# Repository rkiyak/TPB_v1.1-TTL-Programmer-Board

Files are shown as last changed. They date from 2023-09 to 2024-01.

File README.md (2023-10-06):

# TTL Programming Board (TPB v1.1)

This README file provides an introduction and usage guide for your TTL programming board. This board is designed for programming ESP32 boards using the CH340 TTL converter IC.

<p align="center">
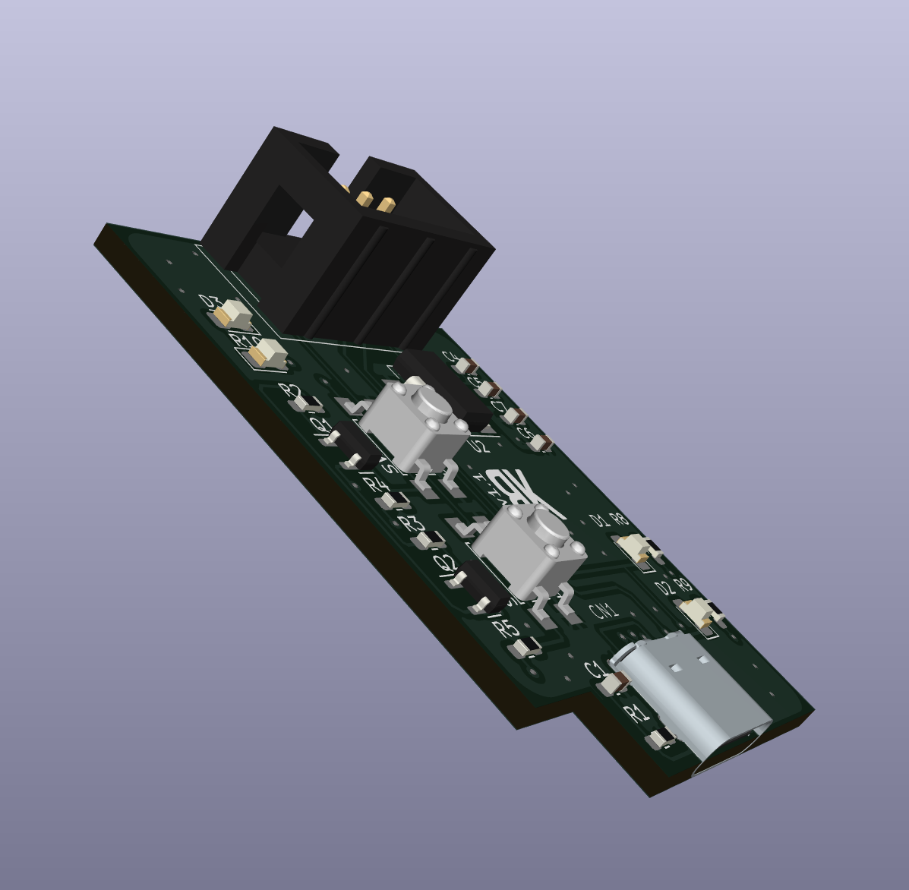
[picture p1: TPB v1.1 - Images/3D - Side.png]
3D Side Image
  
</p>

## Features

- Equipped with the CH340 TTL converter IC for programming ESP32 boards.
- Simple interface for quick and easy use.
- PCB design and connection schematics are provided.

## Connections

### Input Connector (Type-C)
- Input Voltage: 5V

### Programming Connector
The programming connector is used for programming ESP32 boards and has the following pin connections:

1. 3V3
2. TX
3. IO0
4. RX
5. GND
6. EN

These connections define the pins used for programming your ESP32 board. Please make sure to carefully connect to these pins for the programming process.

## Using the Board

Using the board is straightforward. You can program your ESP32 boards by following these steps:

1. Plug the board into the USB port.

2. Connect your ESP32 board to the TTL connection points on the board, ensuring that you follow the connection schematics.

3. Prepare your ESP32 program using Arduino IDE or a similar software.

4. Select the board and upload your program using Arduino IDE or your preferred software.

5. Once the programming process is complete, your ESP32 board is ready for use.

## Images

### Schematic

You can find the connection schematics for the board in the image below:

<p align="center">
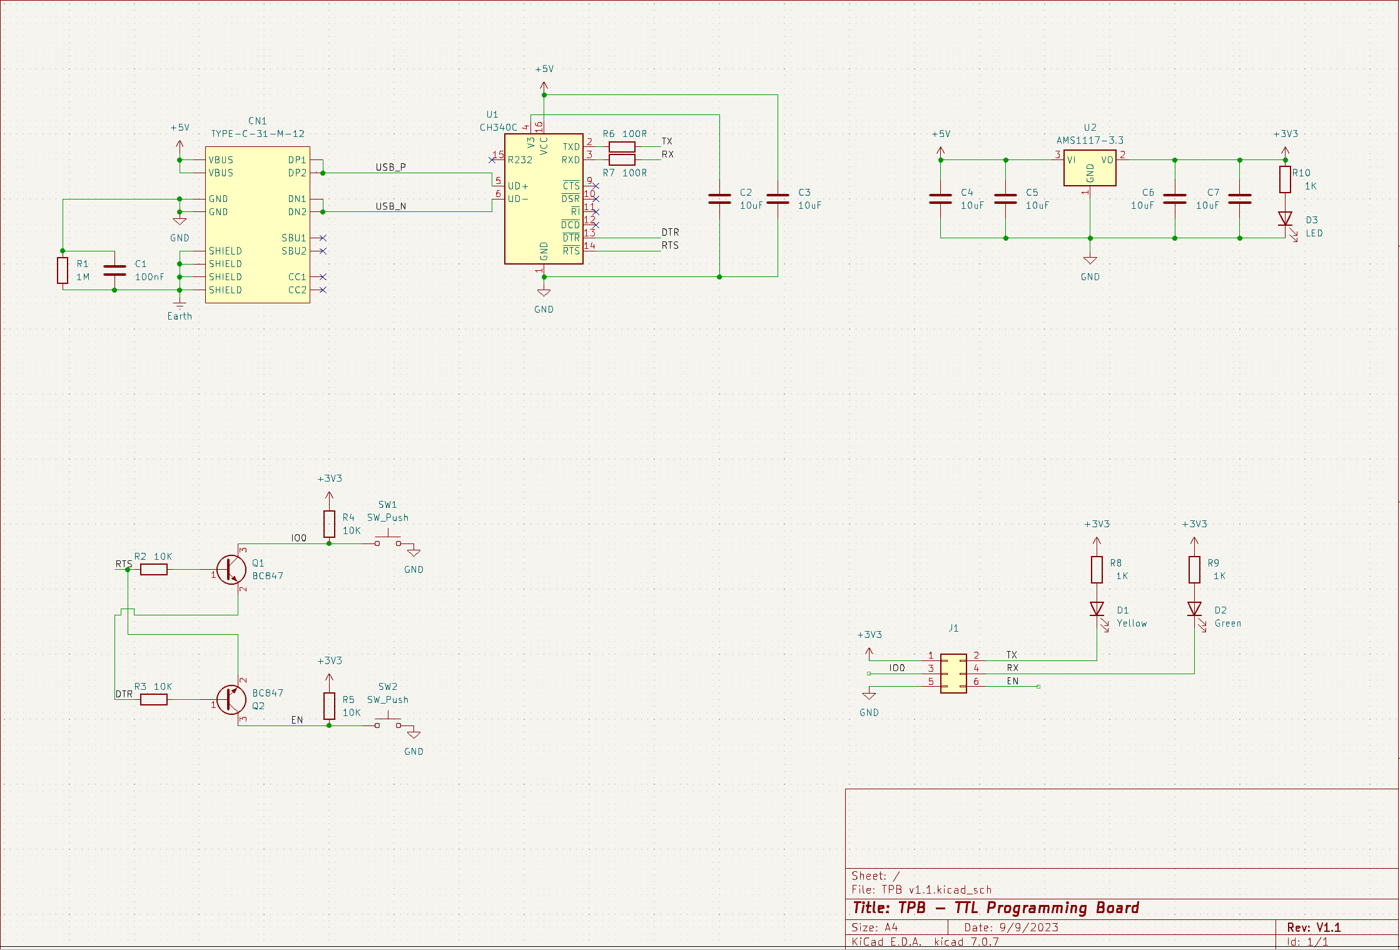
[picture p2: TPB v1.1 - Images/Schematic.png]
Schematic Image
  
</p>

### PCB Images

Below are some images of the board's PCB design:

<p align="center">
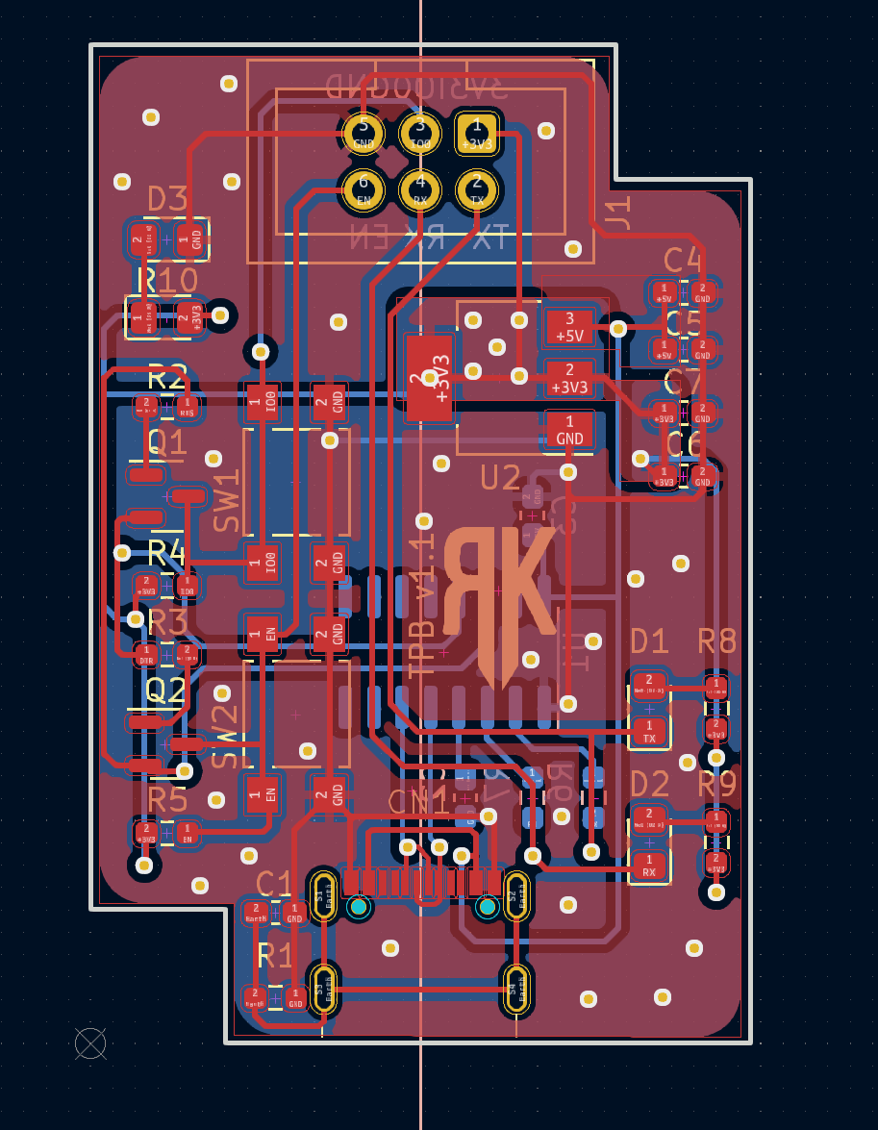
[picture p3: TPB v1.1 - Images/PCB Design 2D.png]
PCB Image 1
  
</p>

### 3D Images

Here are 3D images of the board:

<p align="center">
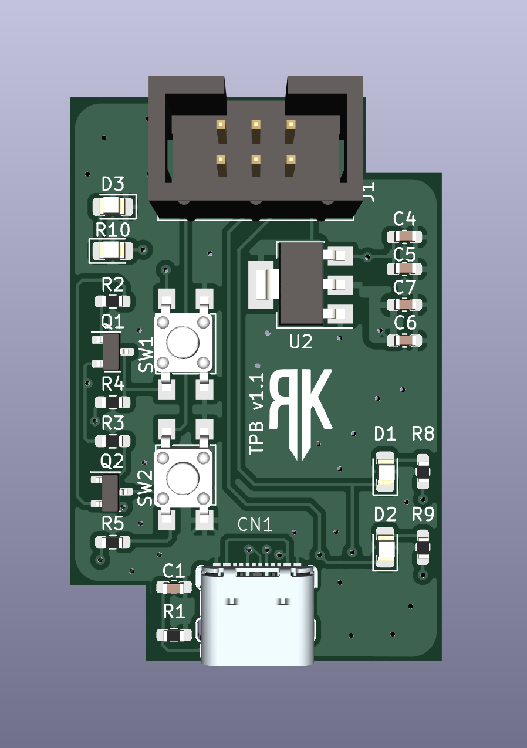
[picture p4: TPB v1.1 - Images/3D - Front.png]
3D Front Image
  
</p>

<p align="center">
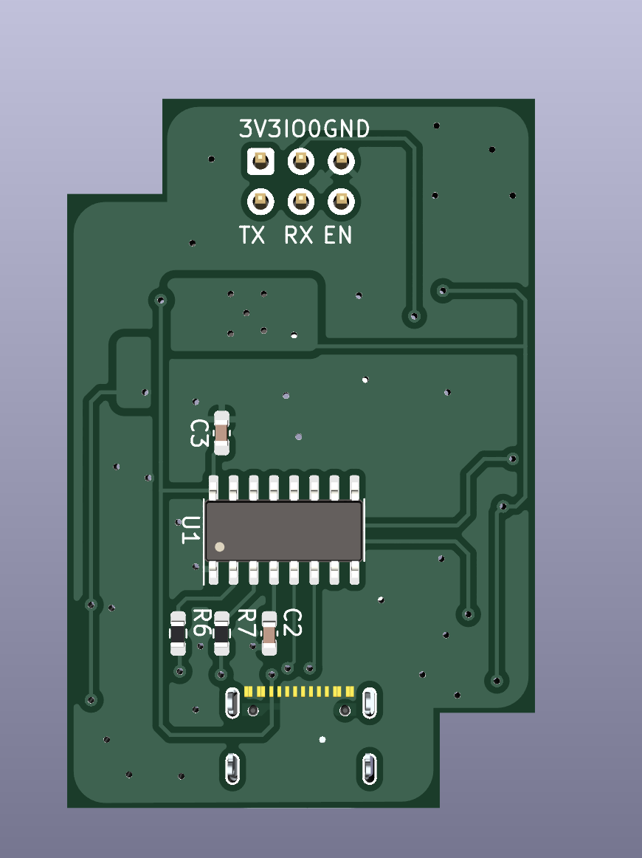
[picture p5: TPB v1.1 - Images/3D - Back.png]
3D Back Image
  
</p>

## Support

If you have any questions or need assistance with using the board, please contact us at rk@rkiyak.com.

## License

The design of this board is licensed under the Open Source license. Please review the license document and ensure compliance before using the board.

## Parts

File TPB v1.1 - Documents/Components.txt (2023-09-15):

Type C USB Connector
https://www.lcsc.com/search?q=TYPE-C-31-M-12

Serial Communication IC
https://www.lcsc.com/product-detail/USB-ICs_WCH-Jiangsu-Qin-Heng-CH340C_C84681.html

Programming Connector

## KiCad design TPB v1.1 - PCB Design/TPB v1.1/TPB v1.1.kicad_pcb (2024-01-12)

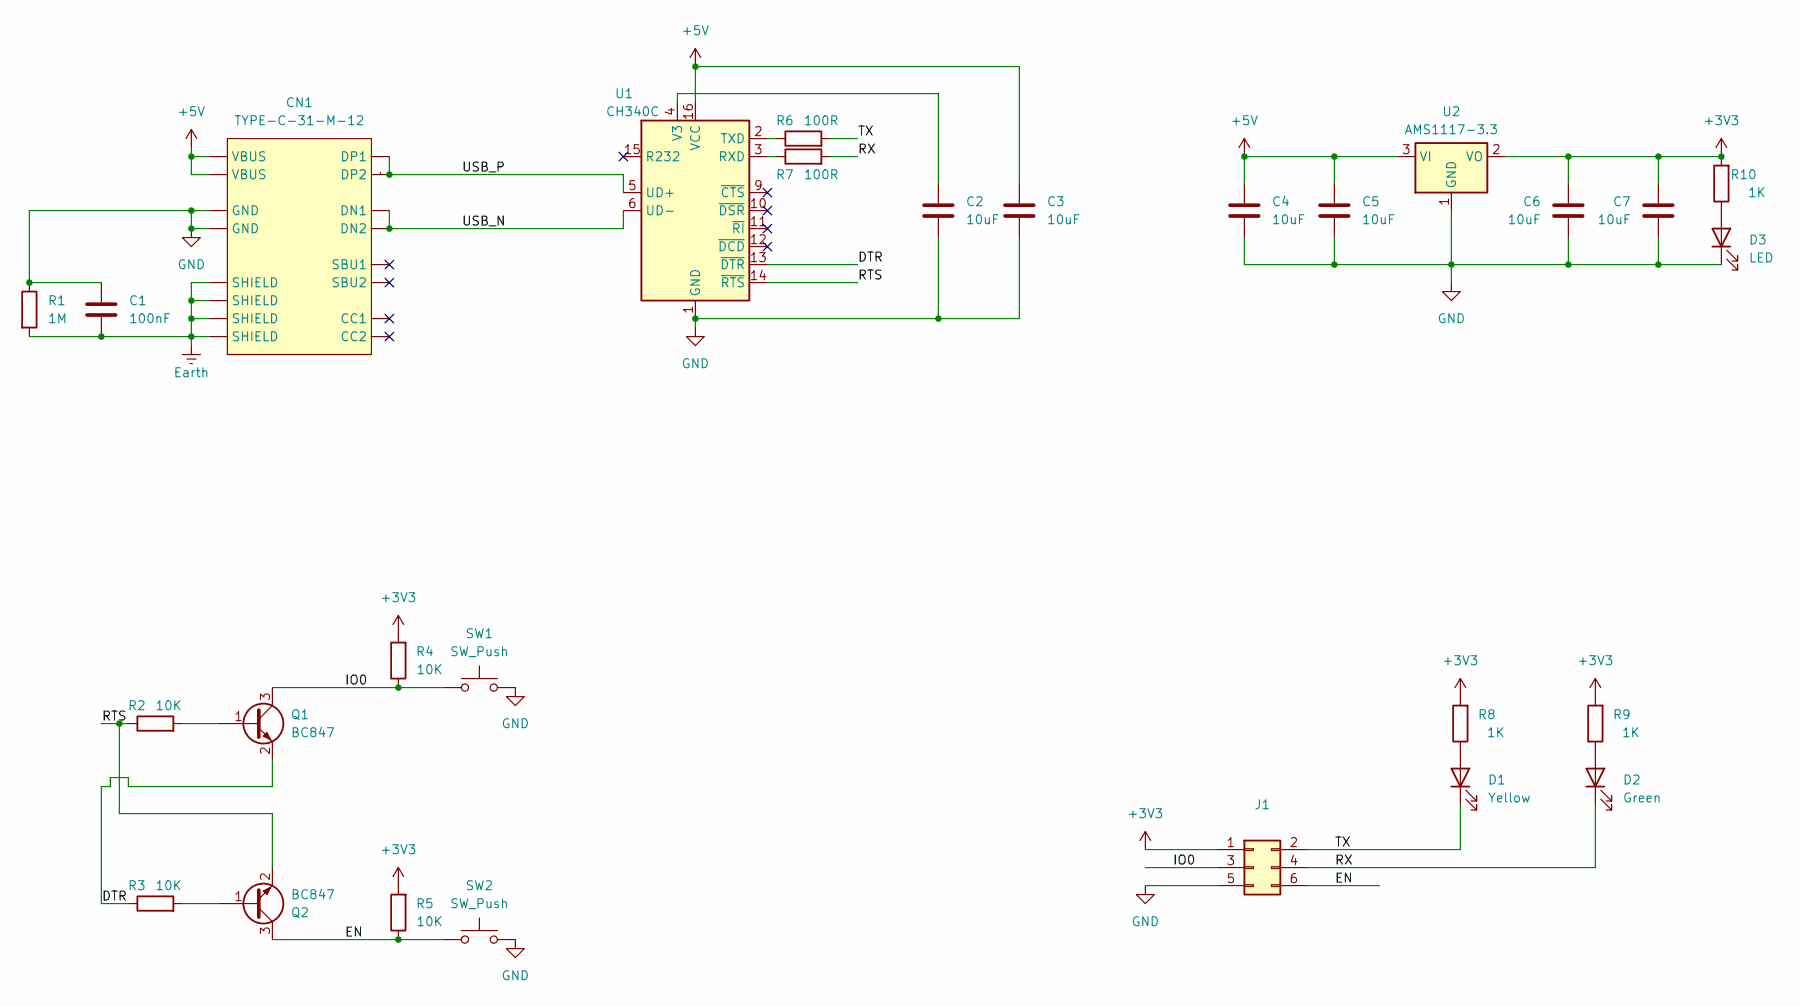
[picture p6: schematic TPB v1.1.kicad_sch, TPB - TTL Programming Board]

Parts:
C1: 100nF; C_0603_1608Metric_Pad1.08x0.95mm_HandSolder; Voltage 50V
C2, C3, C4, C5, C6, C7: 10uF; C_0603_1608Metric_Pad1.08x0.95mm_HandSolder
CN1: TYPE-C-31-M-12
D1: Yellow; LED_0805_2012Metric_Pad1.15x1.40mm_HandSolder
D2: Green; LED_0805_2012Metric_Pad1.15x1.40mm_HandSolder
D3: LED; LED_0805_2012Metric_Pad1.15x1.40mm_HandSolder
J1: IDC-Header_2x03_P2.54mm_Vertical
Q1, Q2: BC847; SOT-23
R1: 1M; R_0603_1608Metric_Pad0.98x0.95mm_HandSolder
R2, R3, R4, R5: 10K; R_0603_1608Metric_Pad0.98x0.95mm_HandSolder
R6, R7: 100R; R_0603_1608Metric_Pad0.98x0.95mm_HandSolder
R8, R9: 1K; R_0603_1608Metric_Pad0.98x0.95mm_HandSolder
R10: 1K; LED_0805_2012Metric_Pad1.15x1.40mm_HandSolder
SW1, SW2: SW_Push; SW_SPST_TL3305C
U1: CH340C; SOIC-16_3.9x9.9mm_P1.27mm
U2: AMS1117-3.3; SOT-223-3_TabPin2

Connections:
+3V3: C6.1, C7.1, J1.1, R4.2, R5.2, R8.2, R9.2, R10.2, U2.2 (VO)
+5V: C3.1, C4.1, C5.1, CN1.A4/B9 (VBUS), CN1.B4/A9 (VBUS), U1.16 (VCC), U2.3 (VI)
/DTR: Q1.2 (E), R3.1, U1.13 (~DTR)
/EN: J1.6, Q2.3 (C), R5.1, SW2.1
/IO0: J1.3, Q1.3 (C), R4.1, SW1.1
/RTS: Q2.2 (E), R2.1, U1.14 (~RTS)
/RX: D2.1 (K), J1.4, R7.2
/TX: D1.1 (K), J1.2, R6.2
/USB_N: CN1.A7 (DN1), CN1.B7 (DN2), U1.6 (UD-)
/USB_P: CN1.A6 (DP1), CN1.B6 (DP2), U1.5 (UD+)
Earth: C1.2, CN1.S1 (SHIELD), CN1.S2 (SHIELD), CN1.S3 (SHIELD), CN1.S4 (SHIELD), R1.2
GND: C1.1, C2.2, C3.2, C4.2, C5.2, C6.2, C7.2, CN1.A1/B12 (GND), CN1.B1/A12 (GND), D3.1 (K), J1.5, R1.1, SW1.2, SW2.2, U1.1 (GND), U2.1 (GND)
unnamed: D1.2 (A), R8.1
unnamed: D2.2 (A), R9.1
unnamed: D3.2 (A), R10.1
unnamed: Q1.1 (B), R2.2
unnamed: Q2.1 (B), R3.2
unnamed: R7.1, U1.3 (RXD)
unnamed: R6.1, U1.2 (TXD)
unnamed: C2.1, U1.4 (V3)

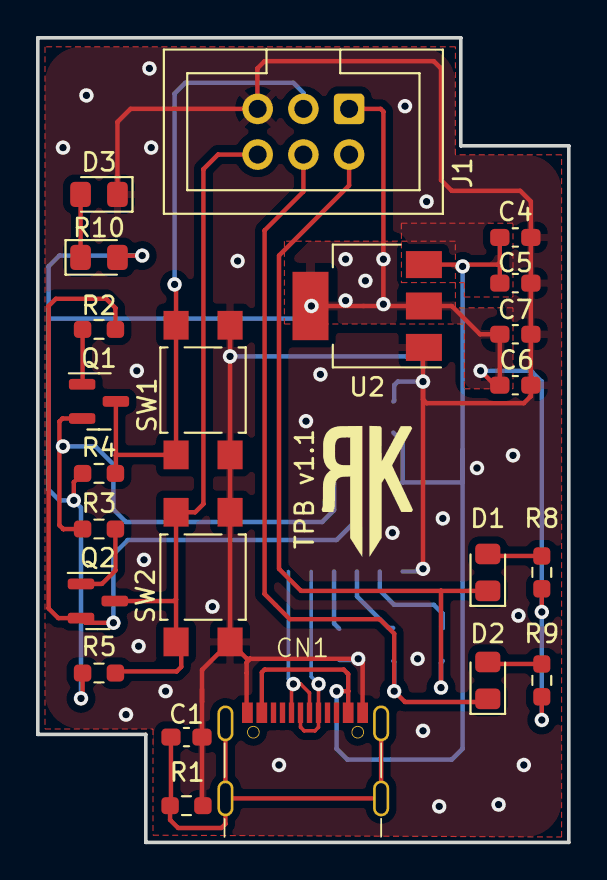
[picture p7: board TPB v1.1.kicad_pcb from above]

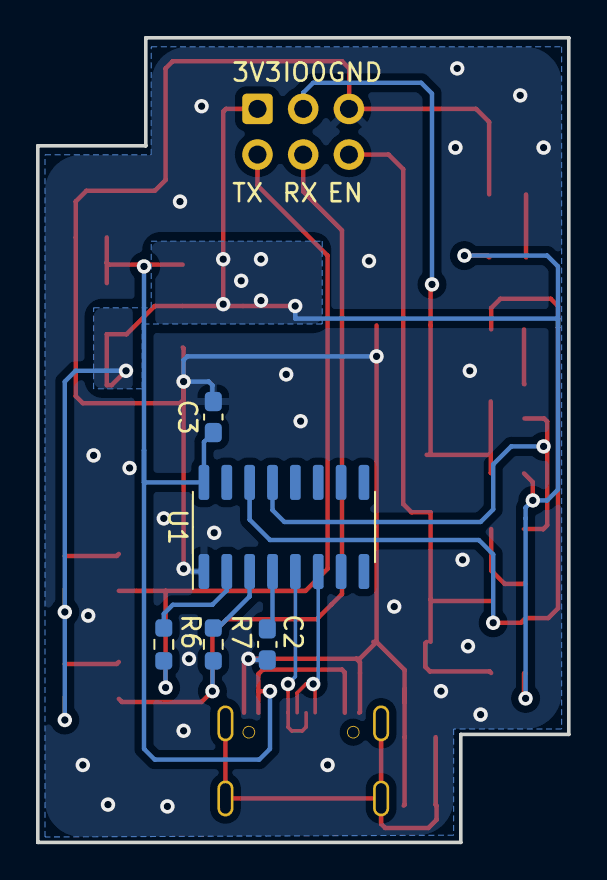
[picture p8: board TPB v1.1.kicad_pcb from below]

Board: 2 copper layers, 29.5 x 44.7 mm, 28 parts (5 on the bottom side), 20 nets.

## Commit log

2023-09-10 PCB Directory Created
    [TPB_v1.1.kicad_pcb, TPB_v1.1.kicad_sch]
2023-09-11 Kicad Project Created
    [TPB_v1.1.kicad_sch]
2023-09-15 Schematic v1
    [TPB v1.1.kicad_pcb, TPB v1.1.kicad_sch, TPB_v1.1.kicad_sch]
2023-09-16 Schematic v2
    [TPB v1.1.kicad_pcb, TPB v1.1.kicad_sch]
2023-09-18 PCB Layout v1
    [TPB v1.1.kicad_pcb, TPB v1.1.kicad_sch]
2023-09-19 Board Outline, Polygon and 3D of Buttons Added
    [TPB v1.1.kicad_pcb, TPB v1.1.kicad_sch]
2023-09-19 Pcb Design Complated
    [TPB v1.1.kicad_pcb]
2023-09-20 DRC Errs Solved
    [TPB v1.1.kicad_pcb]
2023-09-20 Gerber Files Created
    [TPB v1.1-B_Cu.gbl, TPB v1.1-B_Mask.gbs, TPB v1.1-B_Paste.gbp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]
2024-01-12 USB Type C connector 3D Fixed
    [TPB v1.1.kicad_pcb]
